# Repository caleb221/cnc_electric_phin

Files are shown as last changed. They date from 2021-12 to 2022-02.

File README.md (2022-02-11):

# Electric Phin (พิณ)
This is the model for a full sized 3 string electric Phin, a 3 String Thai lute.<br>
Making this instrument required both CNC and 3D printed parts, as well as some hand tools for cleaning things up.<br>

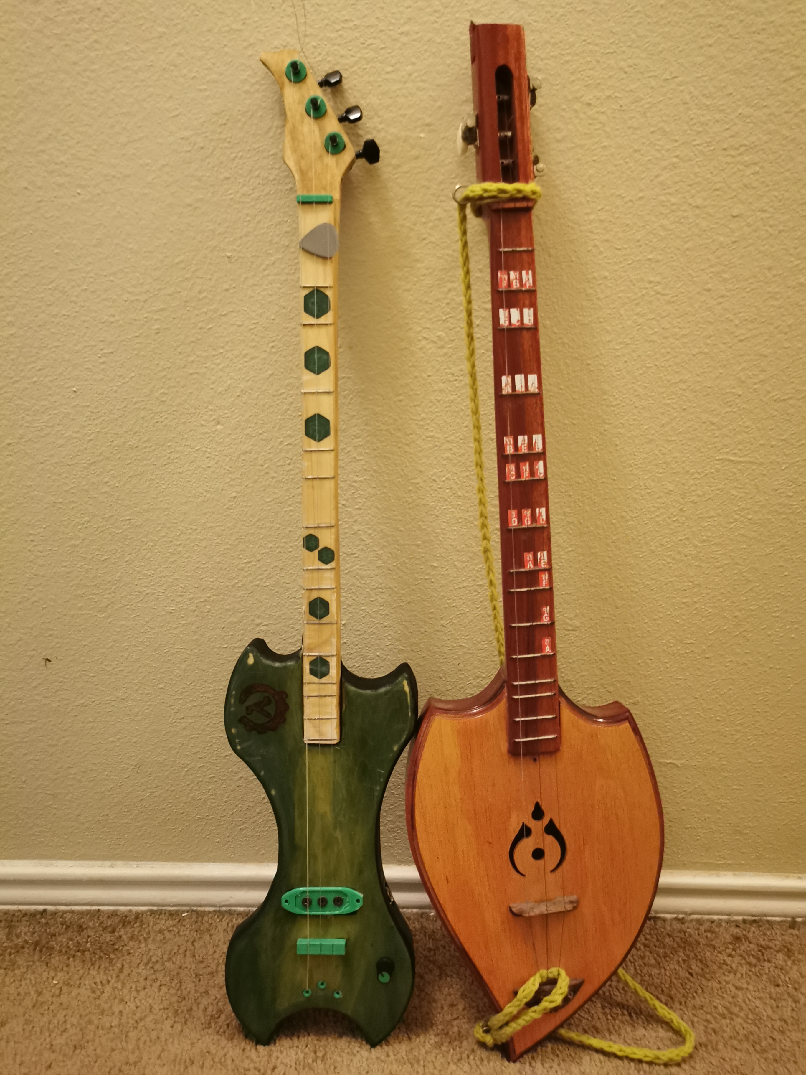
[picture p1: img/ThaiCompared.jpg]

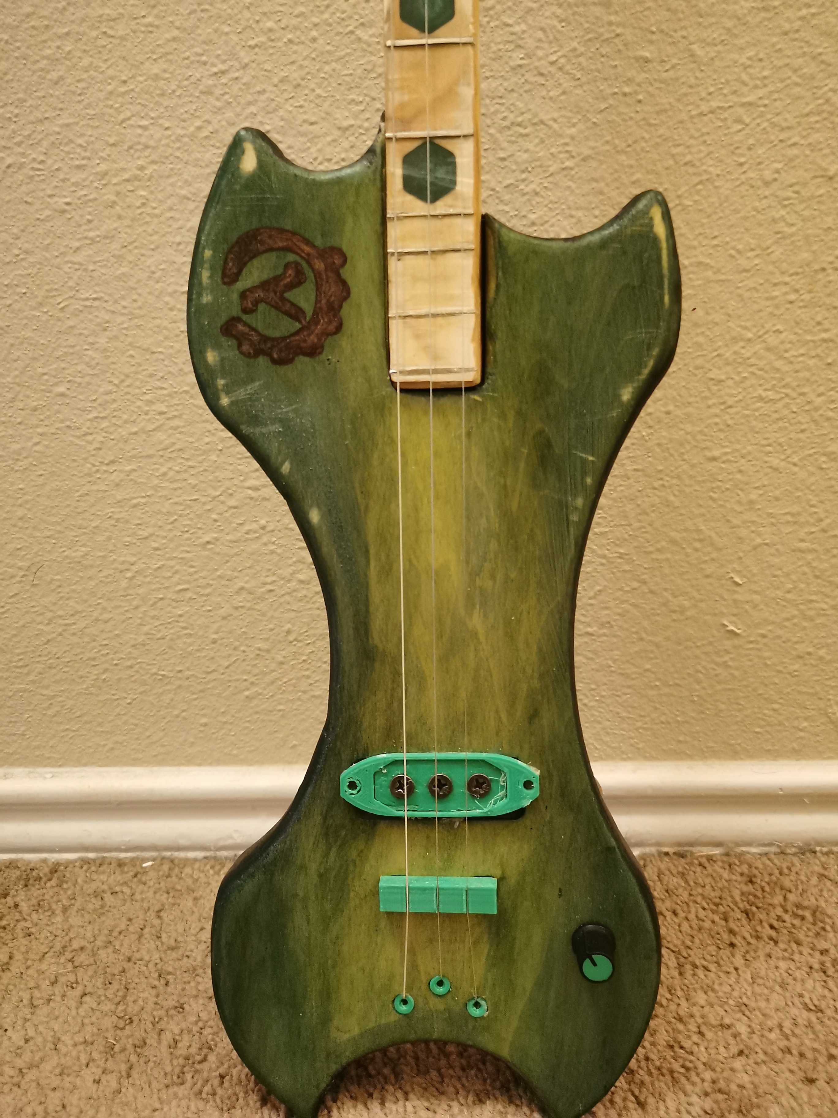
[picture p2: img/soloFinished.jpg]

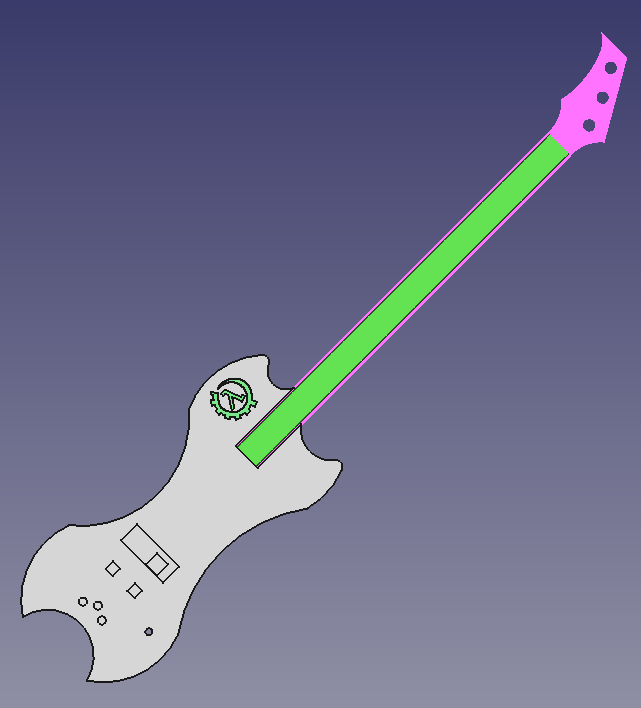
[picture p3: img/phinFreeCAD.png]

<br>
I think you could probably make one using hand tools / a bandsaw / routing table if you wanted to as well!<br>

# Model/CAD
  The model posted here had been created using freeCAD.
  
  The scale length measures at  22'' (558.8mm) and was matches a Phin I had bought in Thailand.
  
  Fret markers were calculated using the <a href="https://www.ekips.org/tools/guitar/fretfind2d/">FretFind2D</a> tool
  
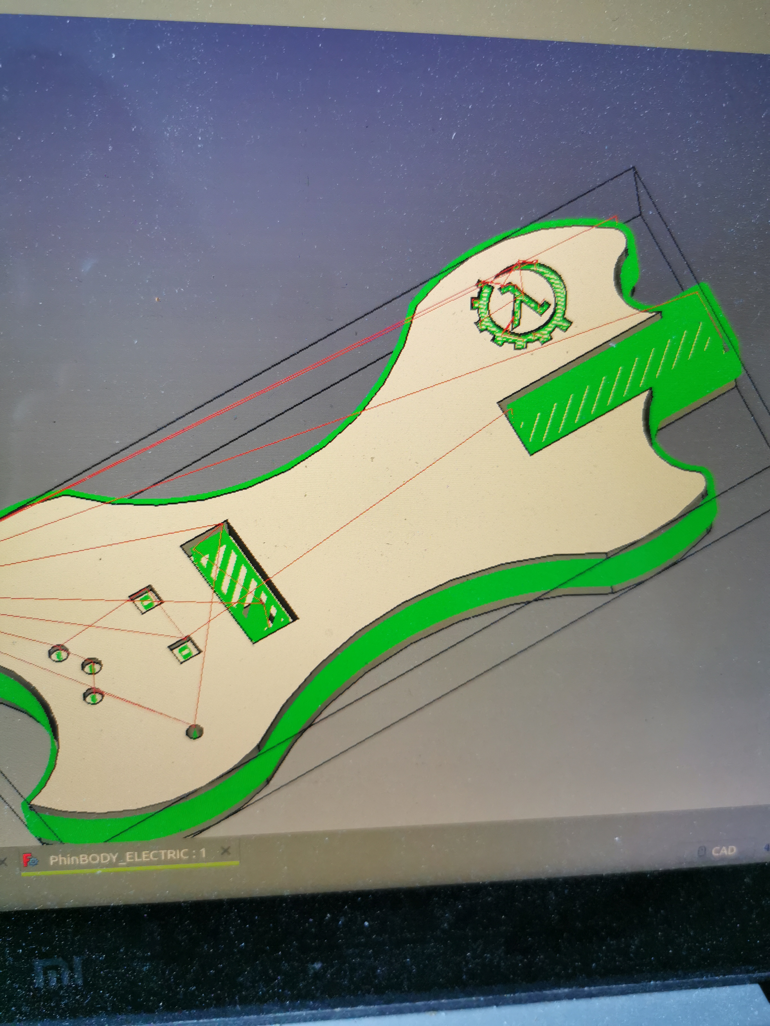
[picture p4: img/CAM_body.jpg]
  
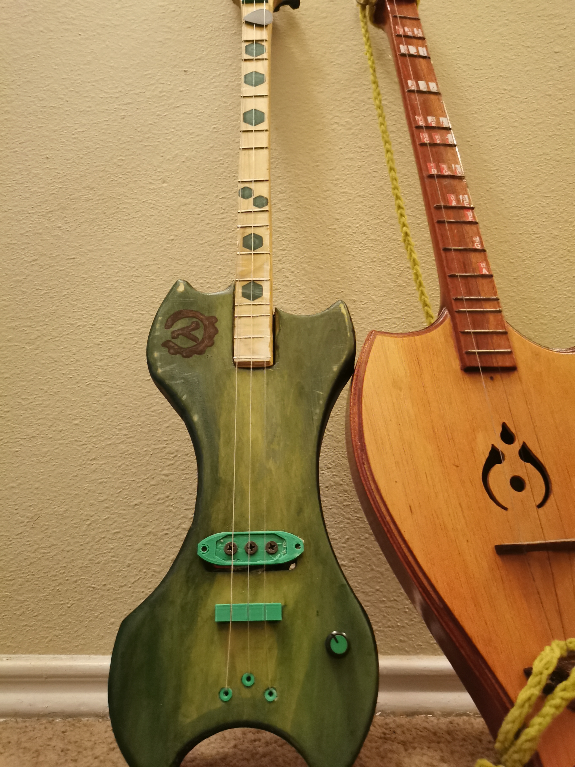
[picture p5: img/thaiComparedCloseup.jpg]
  
  
# Machining/CAM
  Feeds for OPEN BUILDS 1010 LEAD<br>
  Material: Poplar wood (technically hardwood, but still pretty soft)<br>
  
  1/4'' fluted downcut (6mm) bit:   20mm/s,  1200mm/min<br>
  1/8'' fluted downcut (~3mm) bit:  18mm/s,  1080mm/min<br>
  0.5mm Ball nose bit: 15mm/s, 900mm/min<br>
  
  <b>BODY:</b><br>

  Load and Clamp stock (8x3x3'' rectangle board)
  Machine out the inlay if desired<br>
  change bit and then run pickup/neck/electronics pockets<br>
  run the top contour path (this will NOT cut all the way through)<br>
  flip the wood stock<br>
  pocket the electronics back pocket<br>
  finish out the contour from the backside<br>
  remove from machine<br>
  
  sand, stain, do what you want!<br>
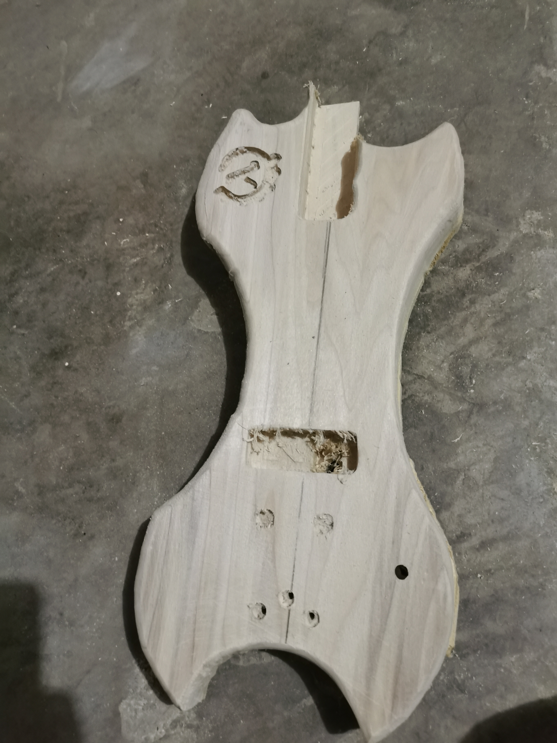
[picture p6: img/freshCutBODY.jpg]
  
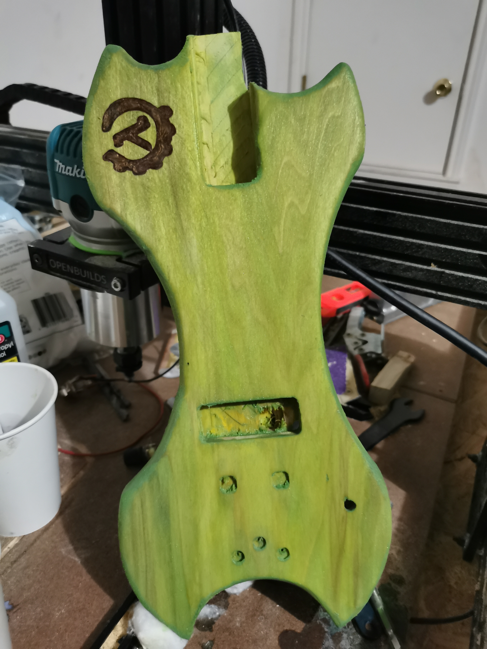
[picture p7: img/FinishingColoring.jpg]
  
  <br><b>Finger Board:</b><br>
    This one requires a bit of patience<br>
    Machine out the inlays<br>
    backfill with epoxy resin and pigment (wait for resin to cure fully before next operation)<br>
    plane out the surface until epoxy overfill and stained parts of wood are even (about 0.5-1.5mm)<br>
    change bit to 0.5mm ball nose and pocket out the fret markers<br>
    take off machine and do the rest of the luthier work on the frets<br>
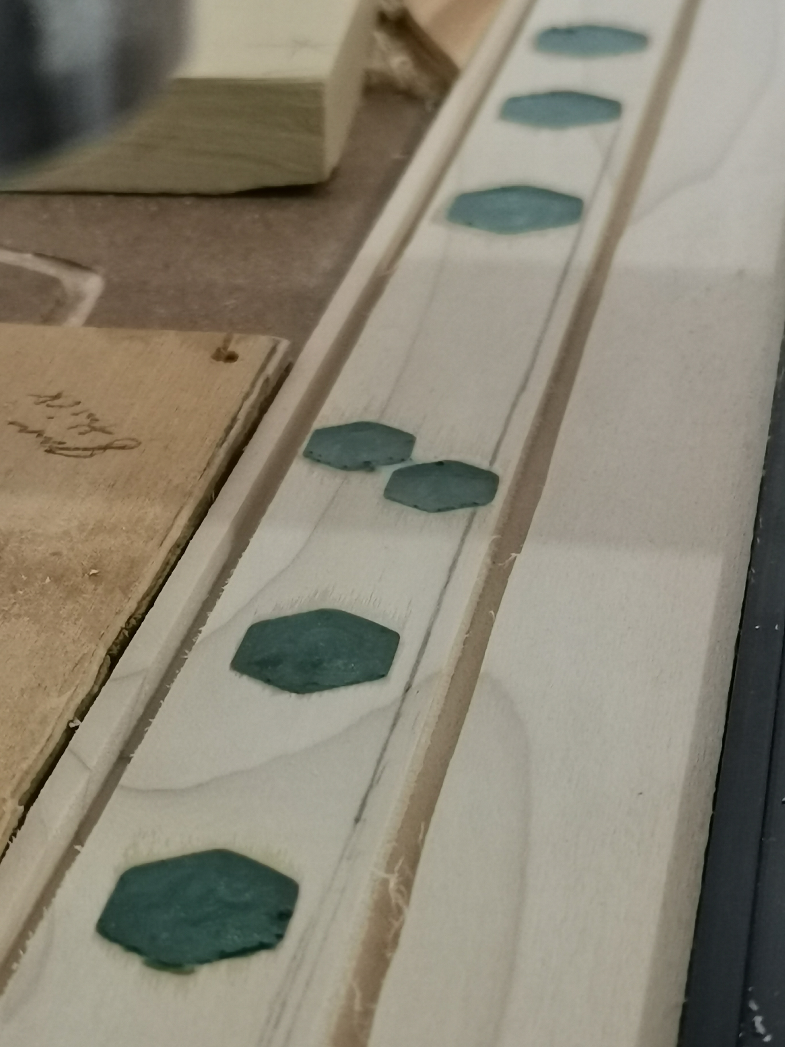
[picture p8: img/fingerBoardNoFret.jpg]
   
   <br><b>Neck:</b><br>
     Clamp stock to workplace<br>
     Machine out the headstock<br>
     Machine out the neck contour<br>
     remove stock from machine<br>
     finish out the backside radius by hand (working on fixing this in the future)<br>

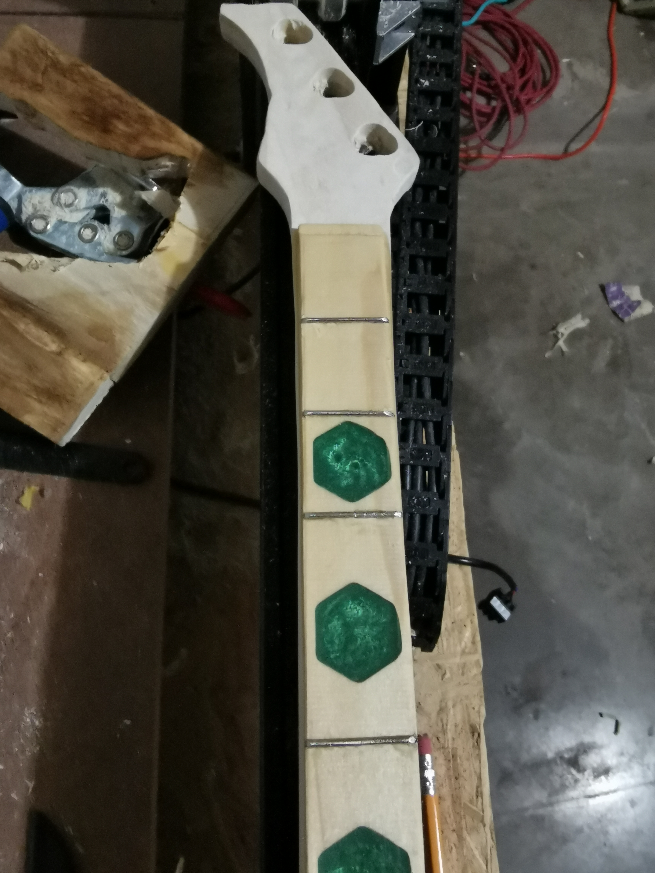
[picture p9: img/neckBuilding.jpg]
   

# Electronics
   <b>Pickups</b><br>
   The pickup bobbins were 3D printed, then neodyium magnets placed in their press-fit spots on the underside.<br>
   #6 iron deck screws were cut to length and placed in the top portion of the bobbin, making good contact with the magnets.<br>
   42 AWG Copper wire was then wrapped around the bobbin until a resistance of about 20K was reached using a multimeter.<br>
   Hot glue was used to "pot" the pickups.<br>

   
   
      
 <br><b>Wiring:</b><br>
 The pickups were wired to a 500K Potentiometer and 1/4'' output jack using the diagram from:<br>
 <a href="https://www.seymourduncan.com/blog/latest-updates/guitar-wiring-102"> Seymour Duncan Wiring Diagram</a>
 <br>
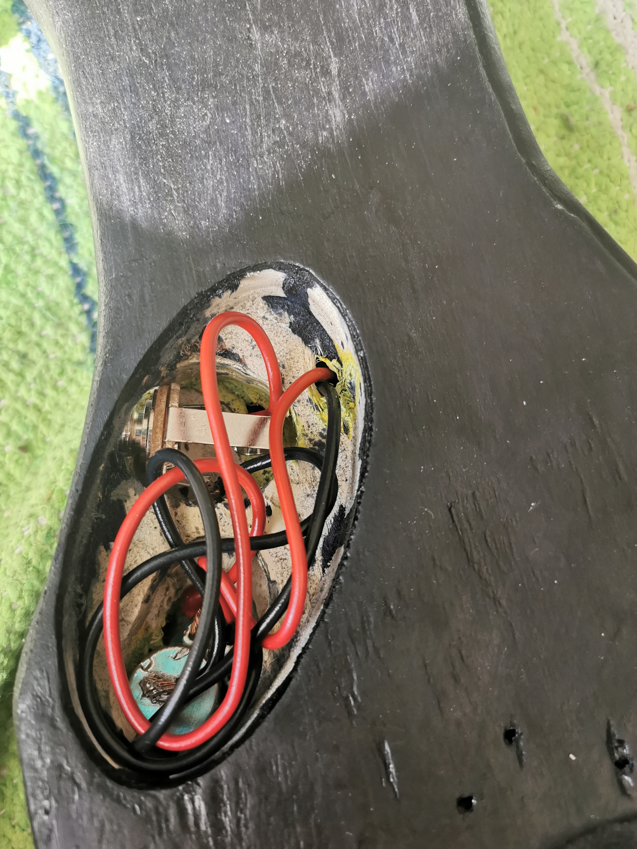
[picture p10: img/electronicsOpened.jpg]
   

# BOM

Materials:<br>
    Wood stock (I used Poplar)<br>
    3x2''     x8'  (back of body, neck, headstock)<br>
    3x1/4''   x2'  (fingerboard)<br>
    1x6''     x1'  (Body front)<br>
    Slim Fretwire<br>
    500K Potentiometer<br>
    42AWG Copper Wire<br>
    20AWG Copper wire<br>
    #6x1' Deck Screws<br>
    1/4'' Standard Audio Input Jack<br>
  
Consumables:<br>
 Epoxy Resin<br>
 Mica Powder<br>
 Keda Wood Dye<br>
 Water based Wood Finish<br>
 Boiled Linseed Oil/Japan Dryer<br>
 Sand Paper<br>
 Safety stuff<br>

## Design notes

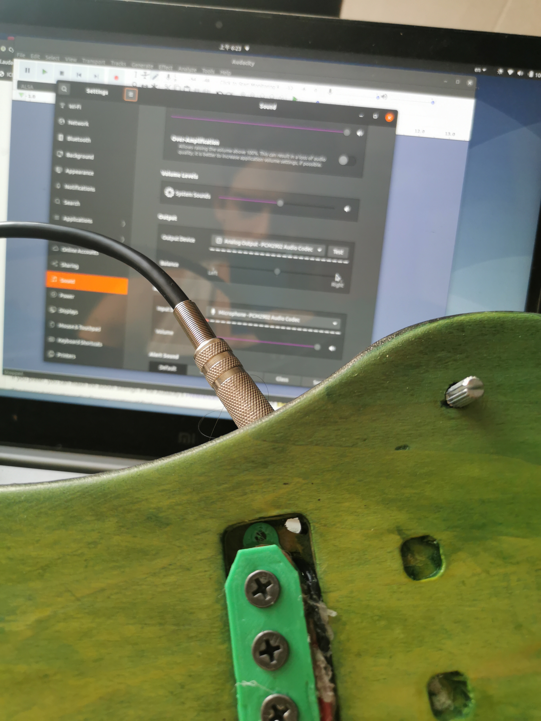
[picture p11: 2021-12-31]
img/pluggedIn.jpg

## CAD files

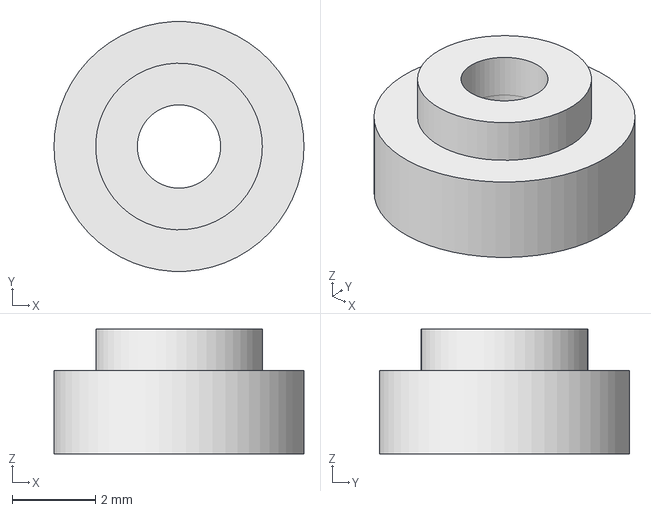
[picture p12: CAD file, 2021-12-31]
CAD/3dPrintFerrules.FCStd
6.00 x 5.99 x 3.00 mm

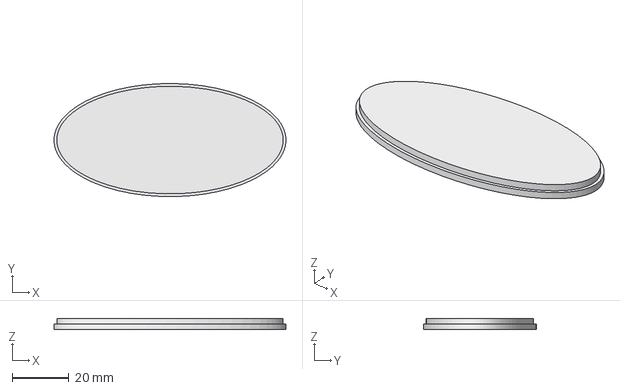
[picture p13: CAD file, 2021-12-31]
CAD/coffinCover.FCStd
82.0 x 40.0 x 4.00 mm

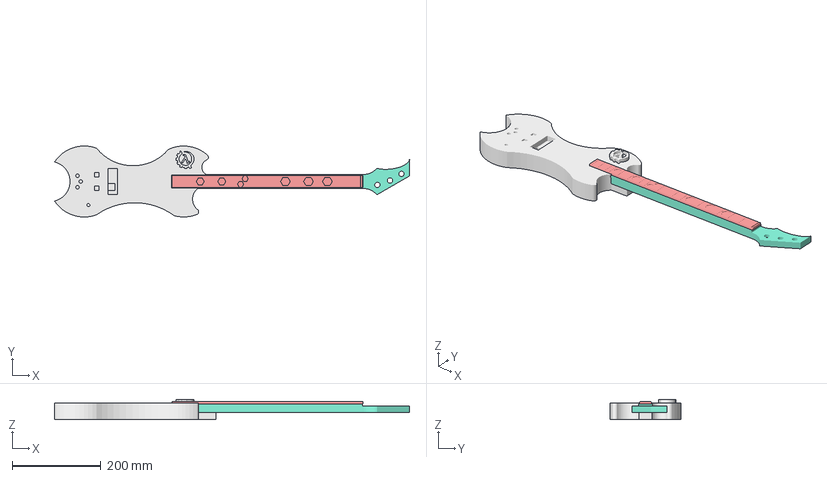
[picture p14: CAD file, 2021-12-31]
CAD/PhinBODY_ELECTRIC.FCStd
799.7 x 160.0 x 46.0 mm
mySymBARRED002 (Solid)001
neck
fingerboard1

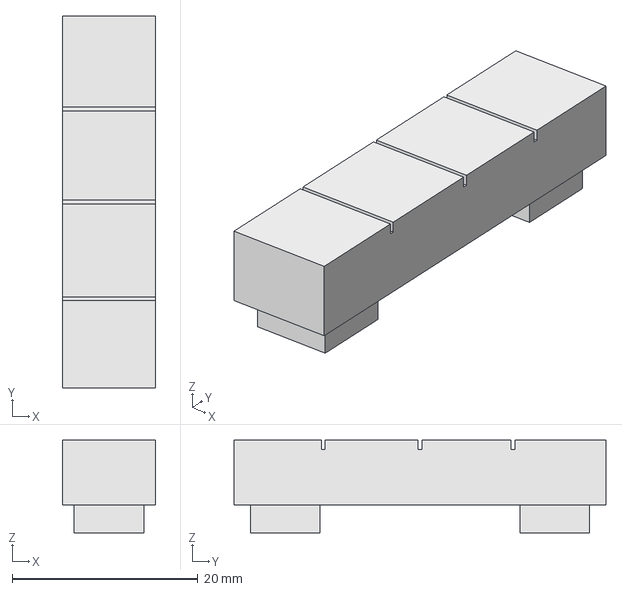
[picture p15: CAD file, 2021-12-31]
CAD/3dPrintBRIDGE.FCStd
10.0 x 40.0 x 10.0 mm

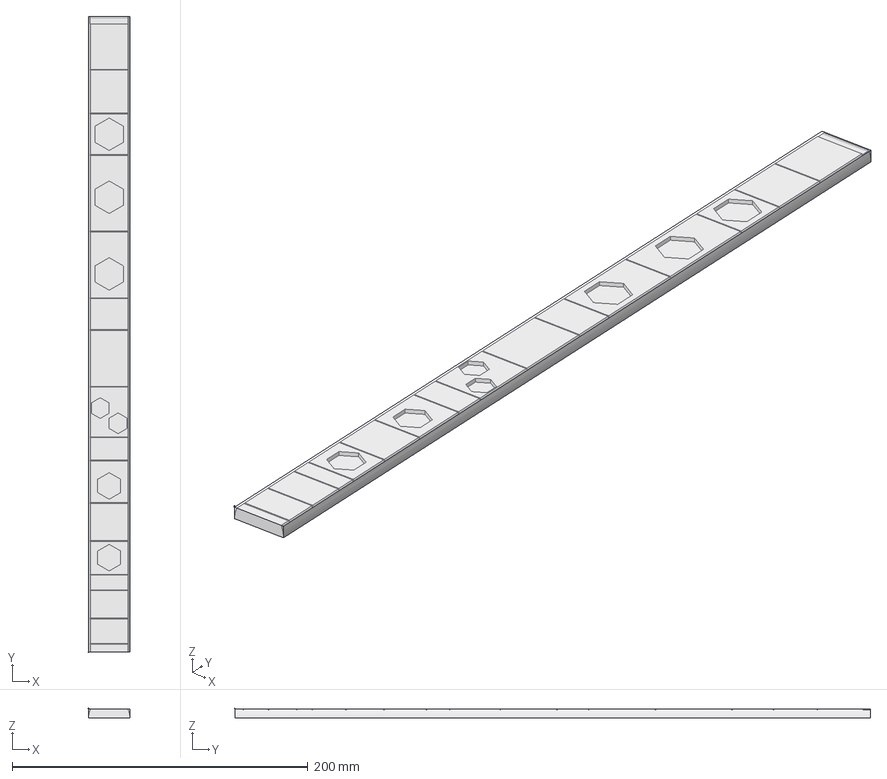
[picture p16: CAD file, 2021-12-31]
CAD/FINGERBOARD_ELECTRIC.FCStd
28.2 x 430.2 x 6.75 mm
Model-Body001
Stock
tool

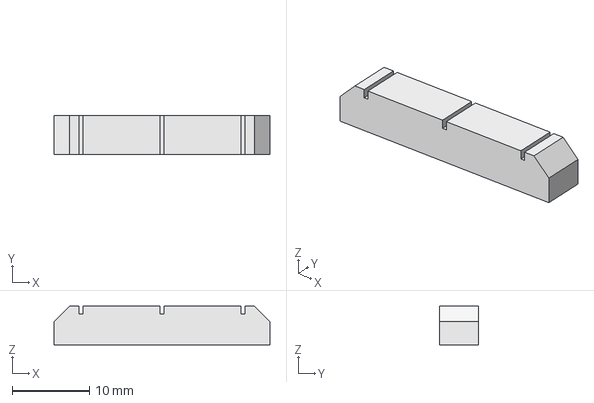
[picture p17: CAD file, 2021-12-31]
CAD/3dPrintNUT_ELECTRIC.FCStd
28.0 x 5.00 x 5.00 mm

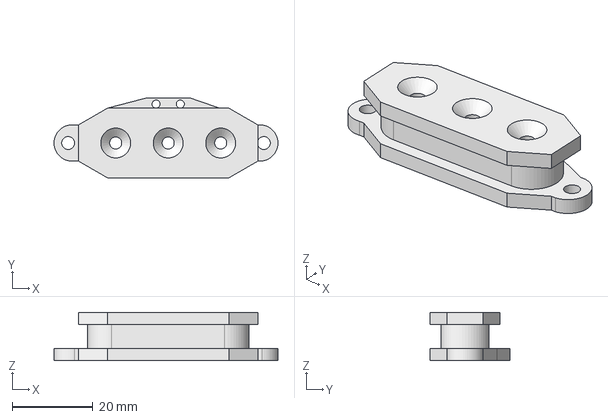
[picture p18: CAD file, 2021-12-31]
CAD/3StringPICKUP_STRAIGHT.FCStd
55.5 x 19.8 x 12.0 mm

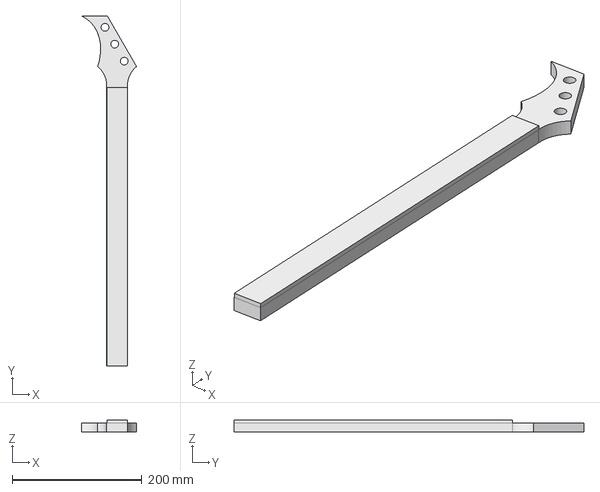
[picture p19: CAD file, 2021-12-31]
CAD/PhinNECK_ELECTRIC.FCStd
85.0 x 540.0 x 19.0 mm
